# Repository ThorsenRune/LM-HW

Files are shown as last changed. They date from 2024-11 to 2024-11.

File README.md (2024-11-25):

# LM-HW
Design files for the LM project
First Version of the LM Hardware

This hardware is part of a neuroprosthesis aimed at restoring hand function in people with tetraplegia.
It is a two channel emg amplifier and a two channel functional electrical stimulator controlled by the ADUCM360 microcontroller.
These are realized using the Eagle version 7 and produced and assembled by EuroCircuits.
The circuits are tested and functional with some minor bug fixes. 

Bug fixes are available upon request

This part of the LM project has been supported by  The Italian Ministry of Health - Ricerca Corrente, the Promobilia Foundation (Sweden) grant no 16066

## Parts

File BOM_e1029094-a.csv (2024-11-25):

Reference:,"e1029094-a"
Date:,"Fri Jul 20 15:37:21 GMT+200 2018"
Generated by:,"Eurocircuits PCBA Visualizer"
Reference designators | Quantity | MPN | Manufacturer | Description
R30 | 1 | GPR06030R | Generic part | 0 Ohms Jumper 0.1W, 1/10W Chip Resistor 0603 (1608 Metric) Moisture Resistant Thick Film
C75, C76 | 2 | C0603C101K5RACTU | Kemet | Capacitor, Ceramic, 100pF 50V 10% X7R
R9, R10, R11, R24, R56, R57, R65, R68, R69, R70, R71, R72 | 12 | GPR0603100K | Generic part | 0603, Res 100.0kOhm, 50V, 1.0%, 100mW
C44, C50, C190, C191 | 4 | 12062C104KAT2A | AVX | 0.1µF ±10% 200V Ceramic Capacitor X7R 1206 (3216 Metric)
C14, C80, C1U15, C1U16, C2U15, C2U16, C19, C20, C23, C24, C28, C31, C40, C41, C42, C45, C48, C49, C53, C67, C82, C86, C88, C90, C144, CU17 | 26 | GPC0603104 | Generic part | 0603, Cap 100.0nF, 50V, 10.0%, X7R
C55 | 1 | GRM32ER60J107ME20L | Murata | 100µF ±20% 6.3V Ceramic Capacitor X5R 1210 (3225 Metric)
R93 | 1 | GPR060310K | Generic part | 0603, Res 10.0kOhm, 50V, 1.0%, 100mW
R12, R13, R16, R17, R22, R43, R46, R77, R144, R145 | 10 | CRCW060310M0FKEA | Vishay | 10M Ohm ±1% 0.1W, 1/10W Chip Resistor 0603 (1608 Metric) Automotive AEC-Q200 Thick Film
R48, R49 | 2 | GPR060310R | Generic part | 0603, Res 10.0Ohm, 50V, 1.0%, 100mW
R7, R8, R21, R61, R67, R89 | 6 | GPR060310K | Generic part | 0603, Res 10.0kOhm, 50V, 1.0%, 100mW
C32, C33 | 2 | C0603C100J5GACTU | Kemet | 10pF ±5% 50V Ceramic Capacitor C0G, NP0 0603 (1608 Metric)
C1, C2, C4, C6, C7, C8, C9, C16, C29, C30, C38, C52, C54, C58, C59, C81 | 16 | C1608X5R0J106M080AB | TDK | 10µF ±20% 6.3V Ceramic Capacitor X5R 0603 (1608 Metric)
R5, R6, R15, R20 | 4 | GPR0603180K | Generic part | 0603, Res 180.0kOhm, 50V, 1.0%, 100mW
R28, R40, R42, R62 | 4 | GPR06031M | Generic part | 0603, Res 1.0MOhm, 50V, 1.0%, 100mW
R23, R25, R29, R41, R55, R63, R80 | 7 | GPR06031K | Generic part | 0603, Res 1.0kOhm, 50V, 1.0%, 100mW
C10, C10A | 2 | 500R14N102JV4T | Johanson Dielectrics Inc. | 1000pF ±5% 50V Ceramic Capacitor C0G, NP0 0603 (1608 Metric) 0.063" L x 0.032" W (1.60mm x 0.81mm)
C22 | 1 | GPC0603105 | Generic part | 0603, Cap 1uF, 50V, 10.0%, X5R
RSENSE | 1 | MCPWR10FTEQ2000 | Multicomp | RES, THICK FILM, 200R, 1%, 0.75W, 2010
C21, C60, C83, C85 | 4 | C0603C224K3RACTU | Kemet | 0.22µF ±10% 25V Ceramic Capacitor X7R 0603 (1608 Metric)
R3 | 1 | GPR0603270K | Generic part | 0603, Res 270.0kOhm, 50V, 1.0%, 100mW
R1, R4 | 2 | GPR06032M | Generic part | 0603, Res 2.0MOhm, 75V, 1.0%, 100mW
C13, C15, C46, C51, C69, C70 | 6 | C5750X7T2E225K250KE | TDK | 2.2µF ±10% 250V Ceramic Capacitor X7T 2220 (5750 Metric)
L2, L3, L4, L5, L6, L8, L9, L10, L21, L22 | 10 | MMZ1608B301CTAH0 | TDK | FERRITE BEAD 300 OHM 0603 1LN
C11, C12, C17, C18 | 4 | C0603C333K1RACTU | Kemet | 0.033µF ±10% 100V Ceramic Capacitor X7R 0603 (1608 Metric)
R66 | 1 | GPR0603390R | Generic part | 0603, Res 390.0Ohm, 50V, 1.0%, 100mW
R2, R90, R91 | 3 | GPR0603390K | Generic part | 0603, Res 390.0kOhm, 75V, 1.0%, 100mW
R14, R73 | 2 | GPR06033K3 | Generic part | 0603, Res 3.3kOhm, 75V, 1.0%, 100mW
C39 | 1 | CGB3B3X5R0J475K055AB | TDK Corporation | 4.7µF ±10% 6.3V Ceramic Capacitor X5R 0603 (1608 Metric) 0.063" L x 0.032" W (1.60mm x 0.80mm)
R19 | 1 | GPR0603470R | Generic part | 0603, Res 470.0Ohm, 75V, 1.0%, 100mW
C26, C27, C34 | 3 | GPC0603474 | Generic part | 0603, Cap 470nF, 50V, 10.0%, X7R
C3, C5 | 2 | GRM219R60J476ME44D | Murata Electronics North America | 47µF ±20% 6.3V Ceramic Capacitor X5R 0805 (2012 Metric) GRM Series
L11, L12 | 2 | LQH31MN470K03L | Murata | 47µH Unshielded Wirewound Inductor 55mA 10.4 Ohm Max 1206 (3216 Metric)
R18 | 1 | MCWR06X4993FTL | Multicomp | RES, THICK FILM, 499KOHM, 1%, 0.1W, 0603
R64 | 1 | GPR06034K7 | Generic part | 0603, Res 4.7kOhm, 50V, 1.0%, 100mW
C43, C47 | 2 | GRM21BR60J475KA11L | Murata | 4.7µF ±10% 6.3V Ceramic Capacitor X5R 0805 (2012 Metric)
L1 | 1 | B82462G4682M000 | EPCOS | 6.8µH Shielded Wirewound Inductor 1.65A 50 mOhm Max Nonstandard
R51, R58, R83, R84 | 4 | GPR0603820R | Generic part | 0603, Res 820.0Ohm, 50V, 1.0%, 100mW
X1 | 1 | ABS05-32.768KHZ-T | Abracon | 32.768kHz ±20ppm Crystal 12.5pF 90 kOhm -40°C ~ 85°C Surface Mount 2-SMD, No Lead
U4, U18 | 2 | AD8232ACPZ-R7 | Analog Device | ECG Front End IC Heart Rate Monitoring 20-LFCSP-WQ (4x4)
U15, U16, U17 | 3 | AD8642ARMZ | Analog Device | IC OPAMP JFET 3.5MHZ RRO 8MSOP
U1, U2 | 2 | MIC5255-3.3YM5-TR | Microchip | Linear Voltage Regulator IC Positive Fixed 1 Output 3.3V 150mA SOT-23-5
U5 | 1 | ADUCM360BCPZ128 | Analog Device | ARM® Cortex®-M3 ADuCM Microcontroller IC 32-Bit 20 MIPS 128KB (128K x 8) FLASH 48-LFCSP-WQ (7x7)
RL3, RL4, RL5, RL6, RL7, RL8, RL9, RL10, RL11, RL12 | 10 | AQY210S | Panasonic | MOSFET Relay, 350 V, 120 mA, 25 ohm, SPST-NO
TR1 | 1 | ATB322524-0110 | TDK | Audio Transformers / Signal Transformers Photoflash Capacitor Charging Transformer
D2, D8, D12, D22 | 4 | BAS40-04W,115 | NXP Semiconductors | Diode Array 1 Pair Series Connection Schottky 40V 120mA (DC) Surface Mount SC-70, SOT-323
D1 | 1 | BAV23S,215 | Nexperia | Diode Array 1 Pair Series Connection Standard 200V 225mA (DC) Surface Mount TO-236-3, SC-59, SOT-23-3
D6N, D6P, D6P1, D6P2 | 4 | BAV3004W-7-F | Diode Inc | Diode Standard 300V 225mA (DC) Surface Mount SOD-123
F1 | 1 | 0805L100WR | Littelfuse | Polymeric PTC Resettable Fuse 6V 1A Ih Surface Mount 0805 (2012 Metric), Concave
ZD1, ZD3 | 2 | KDZLVTFTR150 | ROHM Semiconductor | Zener Diode 150V 1W Surface Mount SOD-123FL
U13 | 1 | LT3484EDCB-1#TRMPBF | Linear Technology/Analog Devices | Photoflash Capacitor Charger PMIC 6-DFN (2x3)
X6 | 1 | 9-215464-0 | TE Connectivity | Connector Header Through Hole 20 position 0.100" (2.54mm)
X4 | 1 | 7-215464-8 | TE Connectivity | Connector Header Through Hole 8 position 0.100" (2.54mm)
IC1 | 1 | OPA340NA/3K | Texas Instruments | General Purpose Amplifier 1 Circuit Rail-to-Rail SOT-23-5
PMOS1 | 1 | SIS406DN-T1-GE3 | Vishay | N-Channel MOSFET 30V 9A (Ta) 1.5W (Ta) Surface Mount PowerPAK® 1212-8
IC17 | 1 | TPS60400DBVR | Texas Instruments | IC, Unregulated 60mA Charge Pump Voltage Inverter
U3 | 1 | TPS61020DRCRG4 | Texas Instrument | DC-DC Switching Boost Step Up Regulator, Adjustable, 900mV-6.5Vin, 1.8V-5.5Vout, 200mAout, SON-10
D21 | 1 | ZHCS400 | Diode Inc | Diode Schottky 40V 400mA (DC) Surface Mount SOD-323
T4 | 1 | ZVN4525ZTA | Diode Inc | N-Channel MOSFET 250V 240mA (Ta) 1.2W (Ta) Surface Mount SOT-89-3
T25 | 1 | ZVP4525ZTA | Diodes Incorporated | P-Channel MOSFET 250V 205mA (Ta) 1.2W (Ta) Surface Mount SOT-89-3

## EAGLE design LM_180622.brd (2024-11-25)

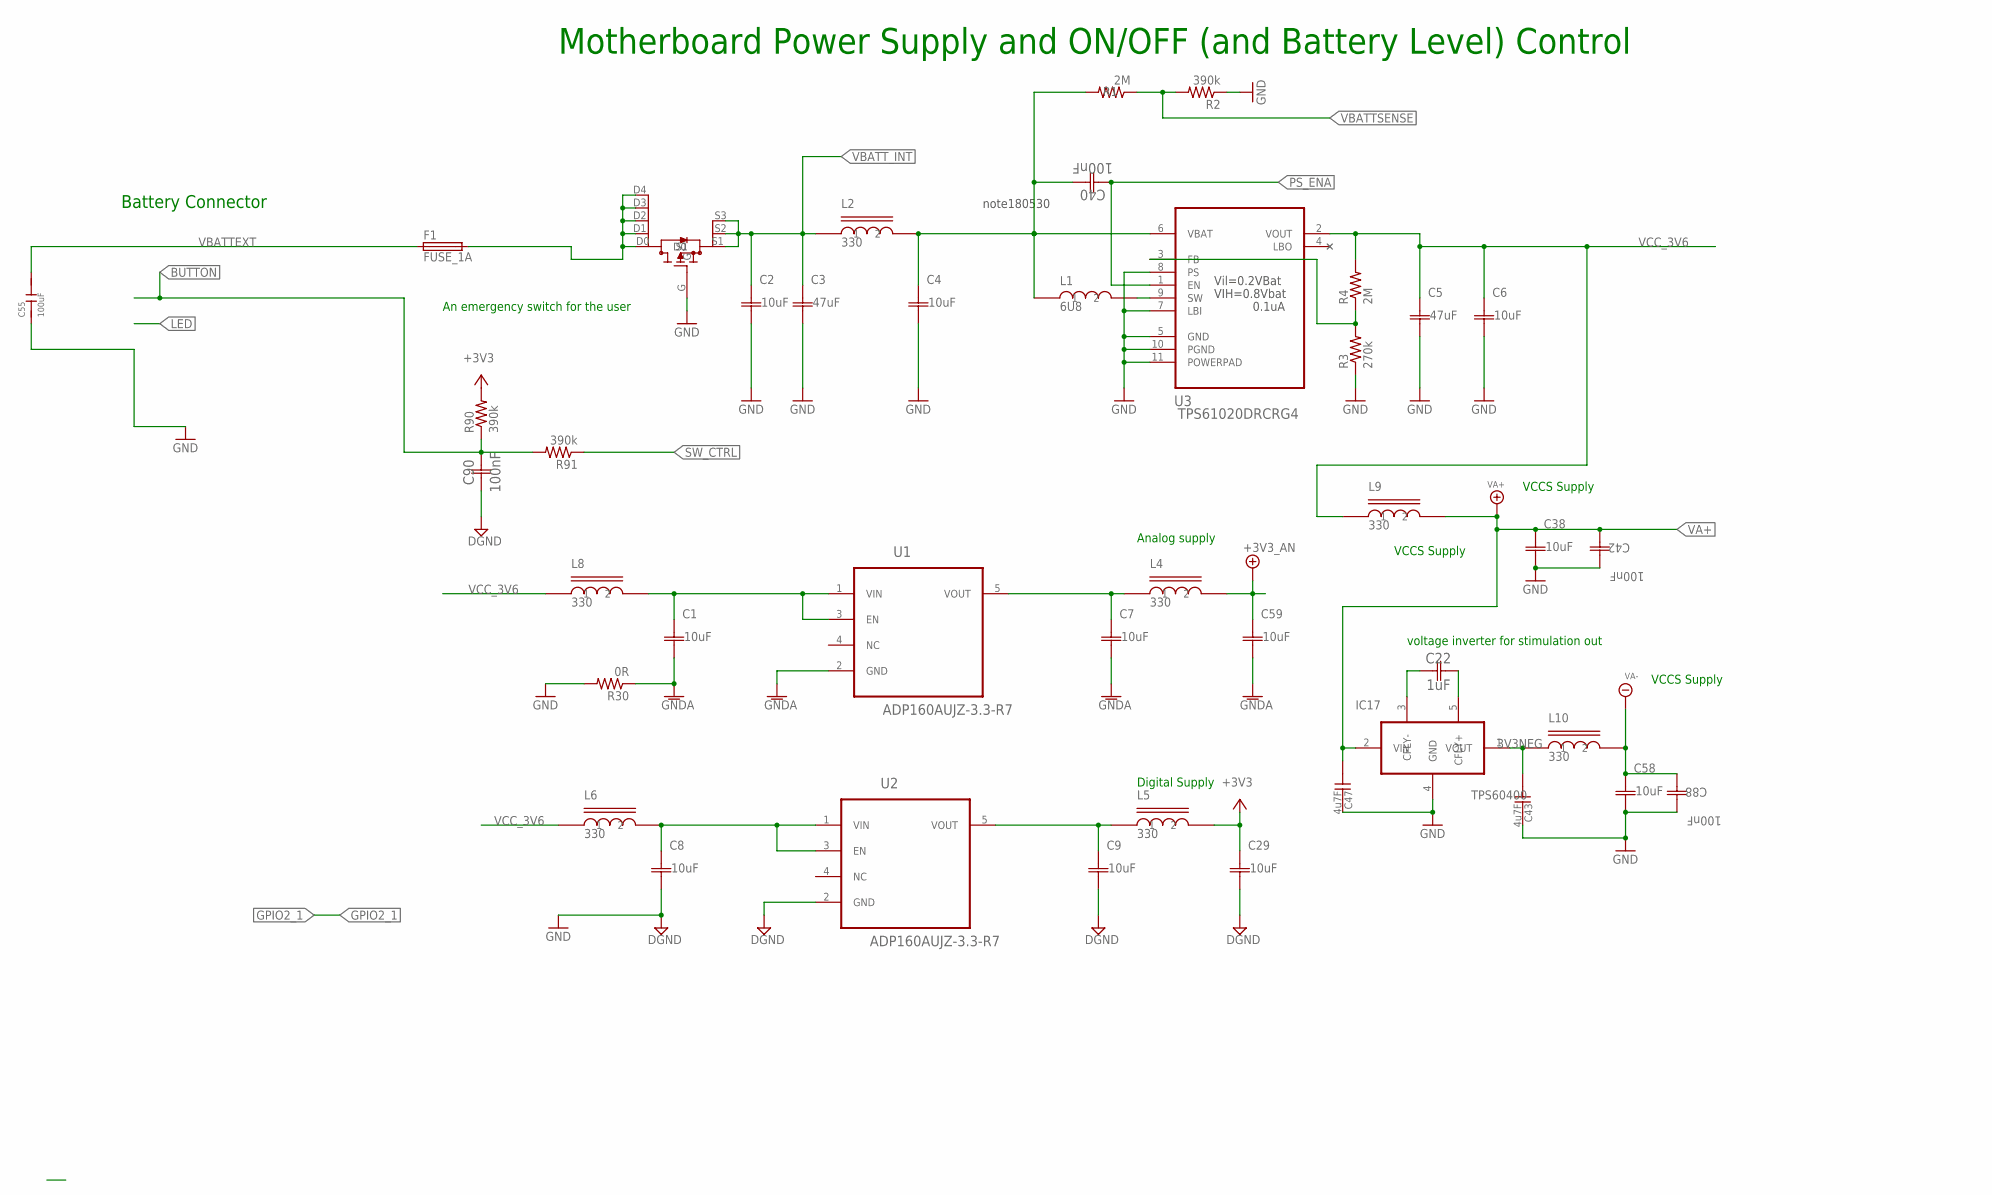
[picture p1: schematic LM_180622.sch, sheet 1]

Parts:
C1, C2, C4, C6, C7, C8, C9, C29, C38, C58, C59: 10uF; C0603
C3, C5: 47uF; C0805
C22: 1uF; 0603-CAP
C40, C42, C88, C90: 100nF; C0603
C43, C47: 4u7F; C0805
C55: 100uF; C1210; MPN JMK325BJ107MY-T
F1: FUSE_1A; C0805
IC17: TPS60400; SOT23-5; MPN TPS60400DBVR
L1: 6U8; SMT_POWER_IND_B82462G4; MPN B82462G4682M000
L2, L4, L5, L6, L8, L9, L10: 330; L0603; PARTNO MMZ1608B301C
PMOS1: SIS407DN; POWERPAK1212-8SINGLE
R1, R4: 2M; R0603
R2, R90, R91: 390k; R0603
R3: 270k; R0603; MPN MC0603N270K500CT
R30: 0R; R0603
U1, U2: ADP160AUJZ-3.3-R7; SOT95P280X100-5N; MPN MIC5255-3.3YM5-TR
U3: TPS61020DRCRG4; SON50P300X300X100-11N

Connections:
3V3NEG: C43.1, IC17.1 (VOUT), L10.1
+3V3: C29.2 (C2), L5.2, R90.2; also elsewhere on the board
+3V3_AN: C59.2 (C2), L4.2; also elsewhere on the board
A3V6: C1.2 (C2), L8.2, U1.1 (VIN), U1.3 (EN)
BUTTON: C90.2 (C2), R90.1, R91.2; also elsewhere on the board
FB_3V6: R3.2, R4.1, U3.3 (FB)
GND: C2.1 (C1), C3.1 (C1), C4.1 (C1), C5.1 (C1), C6.1 (C1), C8.1 (C1), C9.1 (C1), C29.1 (C1), C38.1 (C1), C42.2 (C2), C43.2, C47.2, C55.1, C58.1 (C1), C88.2 (C2), C90.1 (C1), IC17.4 (GND), PMOS1.G, R2.1, R3.1, R30.2, U2.2 (GND), U3.5 (GND), U3.7 (LBI), U3.8 (PS), U3.10 (PGND), U3.11 (POWERPAD); also elsewhere on the board
GNDA: C1.1 (C1), C7.1 (C1), C59.1 (C1), R30.1, U1.2 (GND); also elsewhere on the board
unnamed: F1.2, PMOS1.D0, PMOS1.D1, PMOS1.D2, PMOS1.D3, PMOS1.D4
unnamed: L1.2, U3.9 (SW)
unnamed: C7.2 (C2), L4.1, U1.5 (VOUT)
unnamed: C9.2 (C2), L5.1, U2.5 (VOUT)
unnamed: C8.2 (C2), L6.2, U2.1 (VIN), U2.3 (EN)
unnamed: C22.1 (C1), IC17.3 (CFLY-)
unnamed: C22.2 (C2), IC17.5 (CFLY+)
PS_ENA: C40.1 (C1), U3.1 (EN); also elsewhere on the board
SW_CTRL: R91.1; also elsewhere on the board
VA+: C38.2 (C2), C42.1 (C1), C47.1, IC17.2 (VIN), L9.2; also elsewhere on the board
VA-: C58.2 (C2), C88.1 (C1), L10.2; also elsewhere on the board
VBATTEXT: C55.2, F1.1; also elsewhere on the board
VBATTSENSE: R1.1, R2.2; also elsewhere on the board
VBATT_INT: C2.2 (C2), C3.2 (C2), L2.1, PMOS1.S1, PMOS1.S2, PMOS1.S3; also elsewhere on the board
VBATU3: C4.2 (C2), C40.2 (C2), L1.1, L2.2, R1.2, U3.6 (VBAT)
VCC_3V6: C5.2 (C2), C6.2 (C2), L6.1, L8.1, L9.1, R4.2, U3.2 (VOUT)

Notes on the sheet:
Motherboard Power Supply and ON/OFF (and Battery Level) Control
Battery Connector
An emergency switch for the user
voltage inverter for stimulation out
note180530
Vil=0.2VBat
VIH=0.8Vbat
0.1uA
Digital Supply
Analog supply
VCCS Supply

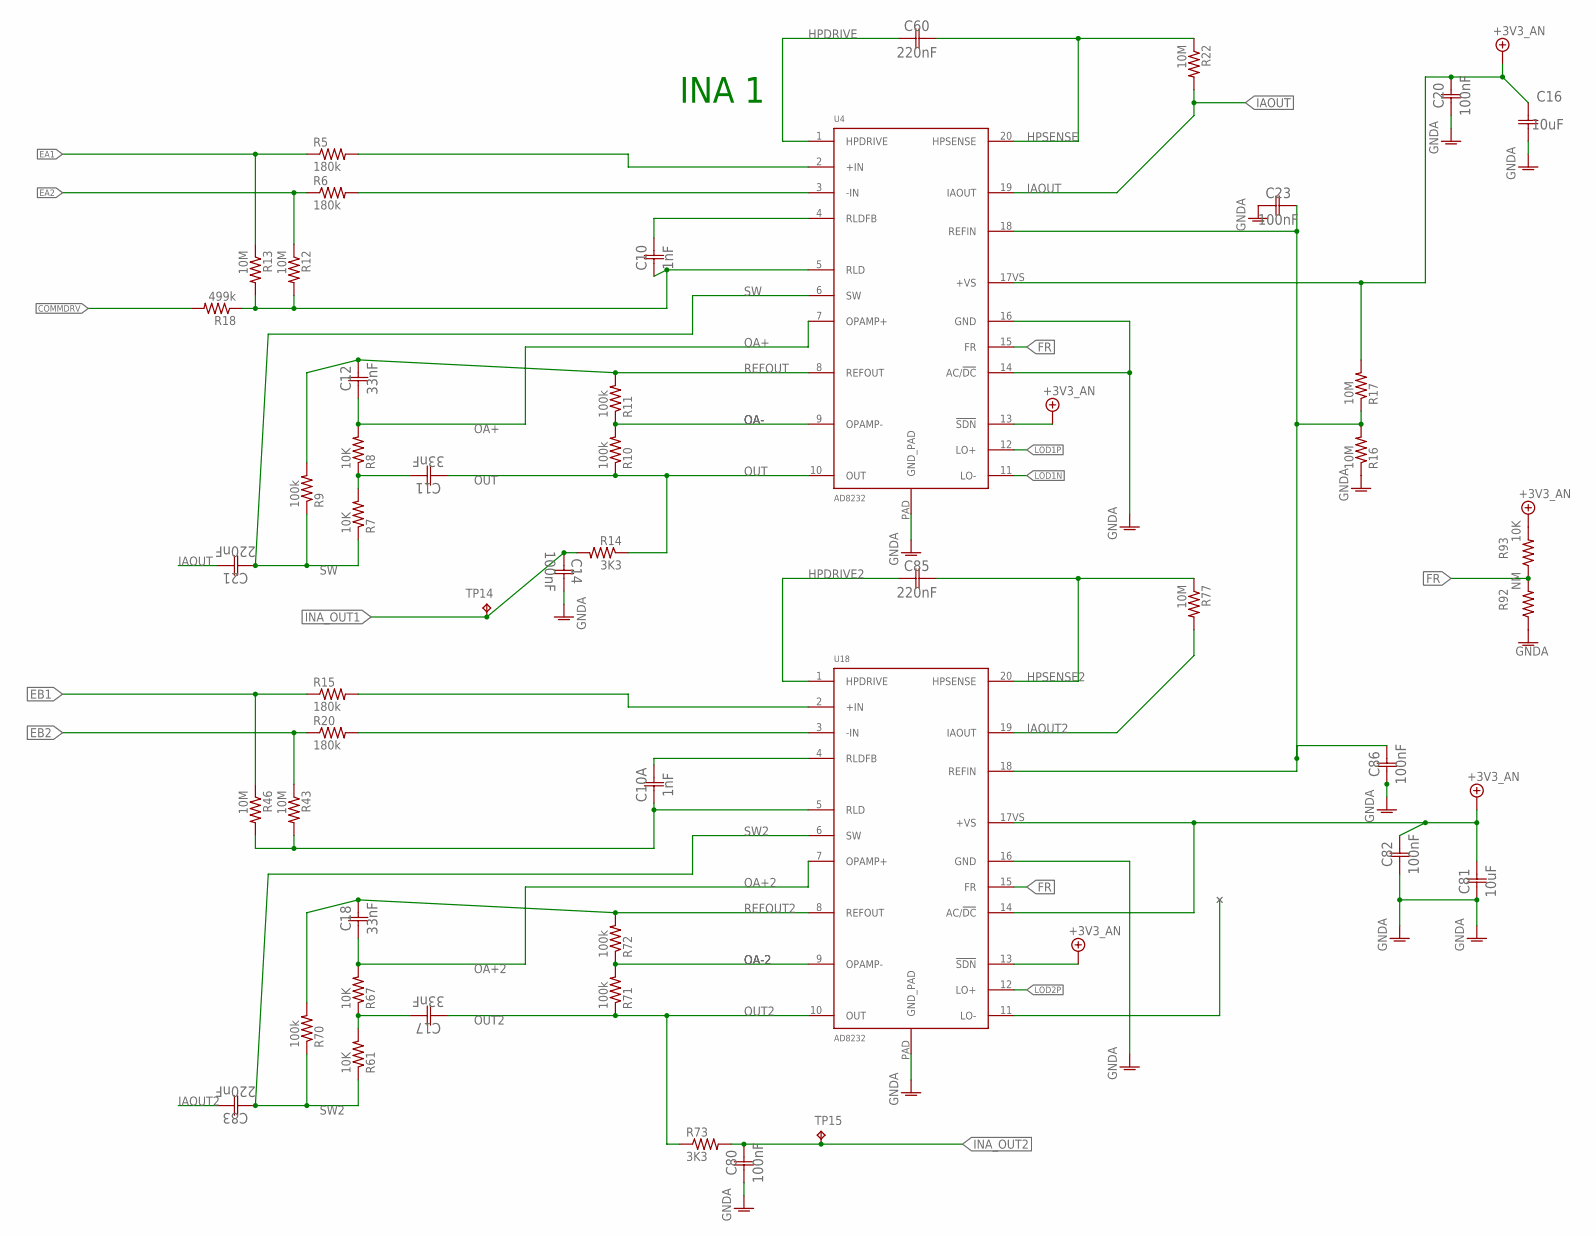
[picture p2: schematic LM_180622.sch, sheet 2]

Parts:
C10, C10A: 1nF; C0603
C11, C12, C17, C18: 33nF; C0603
C14, C20, C23, C80, C82, C86: 100nF; C0603
C16, C81: 10uF; C0603
C21, C60, C83, C85: 220nF; C0603
R5, R6, R15, R20: 180k; R0603
R7, R8, R61, R67, R93: 10K; R0603
R9, R10, R11, R70, R71, R72: 100k; R0603
R12, R13, R16, R17, R22, R43, R46, R77: 10M; R0603
R14, R73: 3K3; R0603
R18: 499k; R0603; MPN CRCW0201499KFKED
R92: NM; R0603
TP14, TP15: NM; B1,27
U4, U18: AD8232; LFCSP_20

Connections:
+3V3_AN: C16.2 (C2), C20.1 (C1), C81.2 (C2), C82.1 (C1), R17.2, R93.2, U4.13 (!SDN), U4.17VS (+VS), U18.13 (!SDN), U18.14 (AC/!DC), U18.17VS (+VS); also elsewhere on the board
COMMDRV: R18.2; also elsewhere on the board
EA1: R5.1, R13.1; also elsewhere on the board
EA2: R6.1, R12.1; also elsewhere on the board
EB1: R15.1, R46.1; also elsewhere on the board
EB2: R20.1, R43.1; also elsewhere on the board
FR: R92.2, R93.1, U4.15 (FR), U18.15 (FR)
GNDA: C14.2 (C2), C16.1 (C1), C20.2 (C2), C23.2 (C2), C80.2 (C2), C81.1 (C1), C82.2 (C2), C86.2 (C2), R16.1, R92.1, U4.14 (AC/!DC), U4.16 (GND), U4.PAD (GND_PAD), U18.16 (GND), U18.PAD (GND_PAD); also elsewhere on the board
HPDRIVE: C60.1 (C1), U4.1 (HPDRIVE)
HPDRIVE2: C85.1 (C1), U18.1 (HPDRIVE)
HPSENSE: C60.2 (C2), R22.1, U4.20 (HPSENSE)
HPSENSE2: C85.2 (C2), R77.1, U18.20 (HPSENSE)
IAOUT: C21.1 (C1), R22.2, U4.19 (IAOUT)
IAOUT2: C83.1 (C1), R77.2, U18.19 (IAOUT)
INA_OUT1: C14.1 (C1), R14.2, TP14.TP; also elsewhere on the board
INA_OUT2: C80.1 (C1), R73.2, TP15.TP; also elsewhere on the board
LOD1N: U4.11 (LO-); also elsewhere on the board
LOD1P: U4.12 (LO+); also elsewhere on the board
LOD2P: U18.12 (LO+); also elsewhere on the board
unnamed: R5.2, U4.2 (+IN)
unnamed: R6.2, U4.3 (-IN)
unnamed: C11.1 (C1), R7.2, R8.1
unnamed: C10A.2 (C2), U18.4 (RLDFB)
unnamed: C10A.1 (C1), R43.2, R46.2, U18.5 (RLD)
unnamed: C10.2 (C2), U4.4 (RLDFB)
unnamed: C10.1 (C1), R12.2, R13.2, R18.1, U4.5 (RLD)
unnamed: R15.2, U18.2 (+IN)
unnamed: R20.2, U18.3 (-IN)
unnamed: C17.1 (C1), R61.2, R67.1
OA+: C12.2 (C2), R8.2, U4.7 (OPAMP+)
OA+2: C18.2 (C2), R67.2, U18.7 (OPAMP+)
OA-: R10.2, R11.1, U4.9 (OPAMP-)
OA-2: R71.2, R72.1, U18.9 (OPAMP-)
OUT: C11.2 (C2), R10.1, R14.1, U4.10 (OUT)
OUT2: C17.2 (C2), R71.1, R73.1, U18.10 (OUT)
REFOUT: C12.1 (C1), R9.2, R11.2, U4.8 (REFOUT)
REFOUT2: C18.1 (C1), R70.2, R72.2, U18.8 (REFOUT)
SW: C21.2 (C2), R7.1, R9.1, U4.6 (SW)
SW2: C83.2 (C2), R61.1, R70.1, U18.6 (SW)
VREFIN: C23.1 (C1), C86.1 (C1), R16.2, R17.1, U4.18 (REFIN), U18.18 (REFIN)

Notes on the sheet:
INA 1

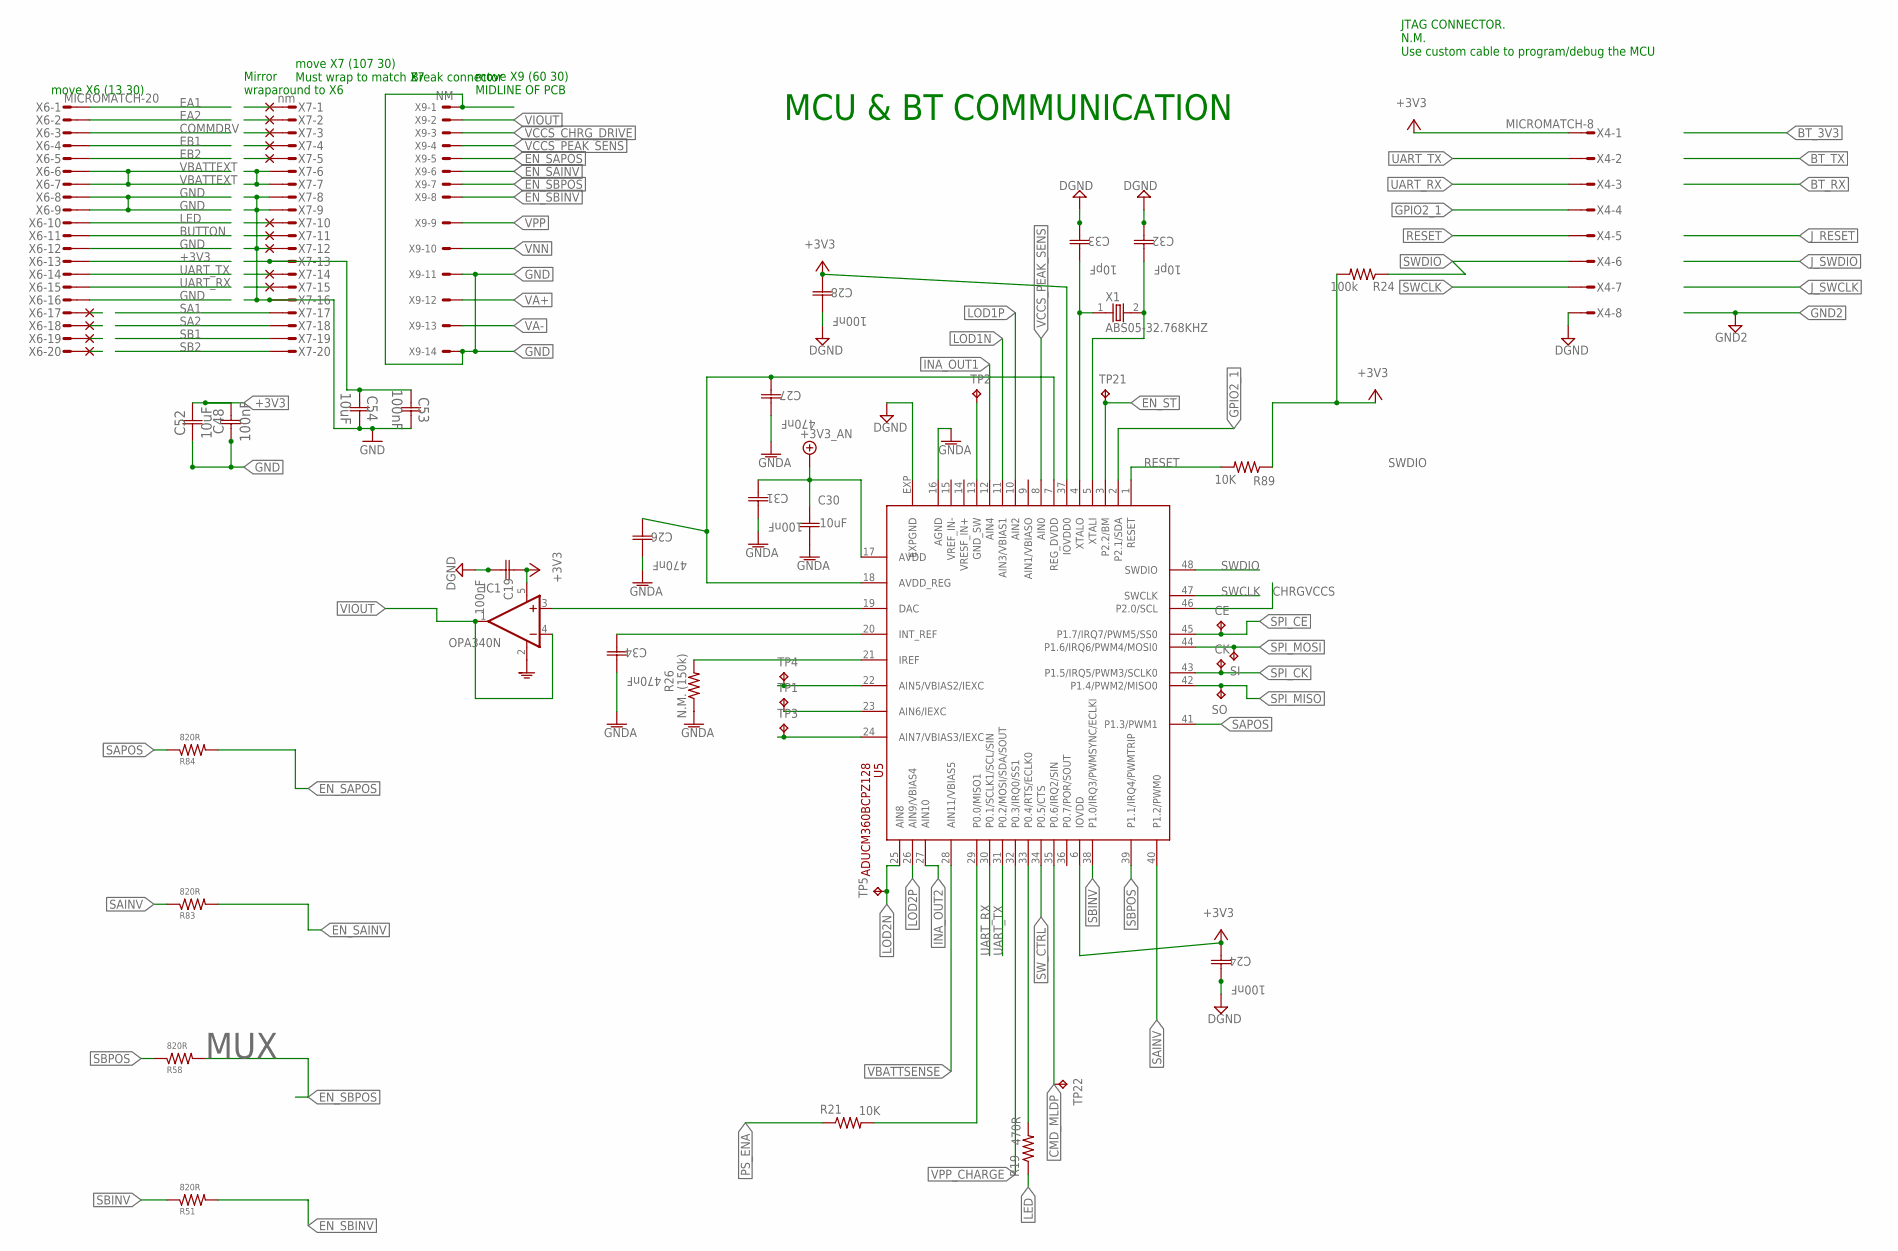
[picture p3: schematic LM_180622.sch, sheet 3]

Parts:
C19, C24, C28, C31, C48, C53: 100nF; C0603
C26, C27, C34: 470nF; C0603
C30, C52, C54: 10uF; C0603
C32, C33: 10pF; C0603
CE: NM; TH0305
CK: NM; TH0305
IC1: OPA340N; SOT23-5; MPN OPA340NA/3K
R19: 470R; R0603; MPN ERJ3EKF4700V
R21, R89: 10K; R0603
R24: 100k; R0603
R26: N.M. (150k); R0603
R51, R58, R83, R84: 820R; R0603
SI: NM; TH0305
SO: NM; TH0305
TP1, TP2, TP3, TP4, TP5, TP21, TP22: NM; TH0305
U5: ADUCM360BCPZ128; LFCSP48; MPN ADUCM360BCPZ128
X1: ABS05-32.768KHZ; CRYSTAL-2PIN
X4: MICROMATCH-8
X6: MICROMATCH-20; MPN 2-215079-0
X7: nm; MICROMATCH-20
X9: NM; 70543-14

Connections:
3V3_BT: C53.2 (C2), C54.1 (C1), X7.13
+3V3: C19.1 (C1), C24.1 (C1), C28.1 (C1), C48.1 (C1), C52.2 (C2), IC1.5 (V+), R24.2, R89.1, U5.6 (IOVDD), U5.37 (IOVDD0), X4.1, X6.13; also elsewhere on the board
+3V3_AN: C30.2 (C2), C31.1 (C1), U5.17 (AVDD); also elsewhere on the board
BUTTON: X6.11; also elsewhere on the board
CHRGVCCS: U5.46 (P2.0/SCL); also elsewhere on the board
CMD_MLDP: TP22.TP, U5.35 (P0.6/IRQ2/SIN)
COMMDRV: X6.3; also elsewhere on the board
EA1: X6.1; also elsewhere on the board
EA2: X6.2; also elsewhere on the board
EB1: X6.4; also elsewhere on the board
EB2: X6.5; also elsewhere on the board
EN_SAINV: R83.2, X9.6; also elsewhere on the board
EN_SAPOS: R84.2, X9.5; also elsewhere on the board
EN_SBINV: R51.2, X9.8; also elsewhere on the board
EN_SBPOS: R58.2, X9.7; also elsewhere on the board
EN_ST: TP21.TP, U5.3 (P2.2/BM)
GND: C19.2 (C2), C24.2 (C2), C28.2 (C2), C32.1 (C1), C33.1 (C1), C48.2 (C2), C52.1 (C1), C53.1 (C1), C54.2 (C2), IC1.2 (V-), U5.EXP (EXPGND), X4.8, X6.8, X6.9, X6.12, X6.16, X7.8, X7.9, X7.12, X7.16, X9.1, X9.11, X9.14; also elsewhere on the board
GNDA: C26.2 (C2), C27.2 (C2), C30.1 (C1), C31.2 (C2), C34.2 (C2), R26.1, U5.16 (AGND); also elsewhere on the board
GPIO2_1: U5.2 (P2.1/SDA), X4.4
INA_OUT1: U5.12 (AIN4); also elsewhere on the board
INA_OUT2: U5.27 (AIN10); also elsewhere on the board
LED: R19.1, X6.10
LED_CTRL1: R19.2, U5.33 (P0.4/RTS/ECLK0)
LOD1N: U5.11 (AIN3/VBIAS1); also elsewhere on the board
LOD1P: U5.10 (AIN2); also elsewhere on the board
LOD2N: TP5.TP, U5.25 (AIN8)
LOD2P: U5.26 (AIN9/VBIAS4); also elsewhere on the board
unnamed: C33.2 (C2), U5.4 (XTALO), X1.1
unnamed: C26.1 (C1), C27.1 (C1), U5.7 (REG_DVDD), U5.18 (AVDD_REG)
unnamed: TP1.TP, U5.23 (AIN6/IEXC)
unnamed: C32.2 (C2), U5.5 (XTALI), X1.2
unnamed: R26.2, U5.21 (IREF)
unnamed: C34.1 (C1), U5.20 (INT_REF)
unnamed: R21.2, U5.29 (P0.0/MISO1)
unnamed: TP2.TP, U5.13 (GND_SW)
unnamed: X7.6, X7.7
unnamed: IC1.3 (+IN), U5.19 (DAC)
unnamed: TP3.TP, U5.24 (AIN7/VBIAS3/IEXC)
unnamed: TP4.TP, U5.22 (AIN5/VBIAS2/IEXC)
PS_ENA: R21.1; also elsewhere on the board
RESET: R89.2, U5.1 (RESET), X4.5
SA1: X7.17; also elsewhere on the board
SA2: X7.18; also elsewhere on the board
SAINV: R83.1, U5.40 (P1.2/PWM0)
SAPOS: R84.1, U5.41 (P1.3/PWM1)
SB1: X7.19; also elsewhere on the board
SB2: X7.20; also elsewhere on the board
SBINV: R51.1, U5.38 (P1.0/IRQ3/PWMSYNC/ECLKI)
SBPOS: R58.1, U5.39 (P1.1/IRQ4/PWMTRIP)
SPI_CE: CE.TP, U5.45 (P1.7/IRQ7/PWM5/SS0)
SPI_CK: CK.TP, U5.43 (P1.5/IRQ5/PWM3/SCLK0)
SPI_MISO: SO.TP, U5.42 (P1.4/PWM2/MISO0)
SPI_MOSI: SI.TP, U5.44 (P1.6/IRQ6/PWM4/MOSI0)
SWCLK: U5.47 (SWCLK), X4.7
SWDIO: R24.1, U5.48 (SWDIO), X4.6
SW_CTRL: U5.34 (P0.5/CTS); also elsewhere on the board
UART_RX: U5.30 (P0.1/SCLK1/SCL/SIN), X4.3, X6.15
UART_TX: U5.31 (P0.2/MOSI/SDA/SOUT), X4.2, X6.14
VA+: X9.12; also elsewhere on the board
VA-: X9.13; also elsewhere on the board
VBATTEXT: X6.6, X6.7; also elsewhere on the board
VBATTSENSE: U5.28 (AIN11/VBIAS5); also elsewhere on the board
VCCS_CHRG_DRIVE: X9.3; also elsewhere on the board
VCCS_PEAK_SENS: U5.8 (AIN0), X9.4; also elsewhere on the board
VIOUT: IC1.1 (OUT), IC1.4 (-IN), X9.2; also elsewhere on the board
VNN: X9.10; also elsewhere on the board
VPP: X9.9; also elsewhere on the board
VPP_CHARGE: U5.32 (P0.3/IRQ0/SS1); also elsewhere on the board

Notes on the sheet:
MCU & BT COMMUNICATION
JTAG CONNECTOR. N.M. Use custom cable to program/debug the MCU
MUX
Break connector
Mirror wraparound to X6
move X9 (60 30) MIDLINE OF PCB
move X6 (13 30)
move X7 (107 30) Must wrap to match X7

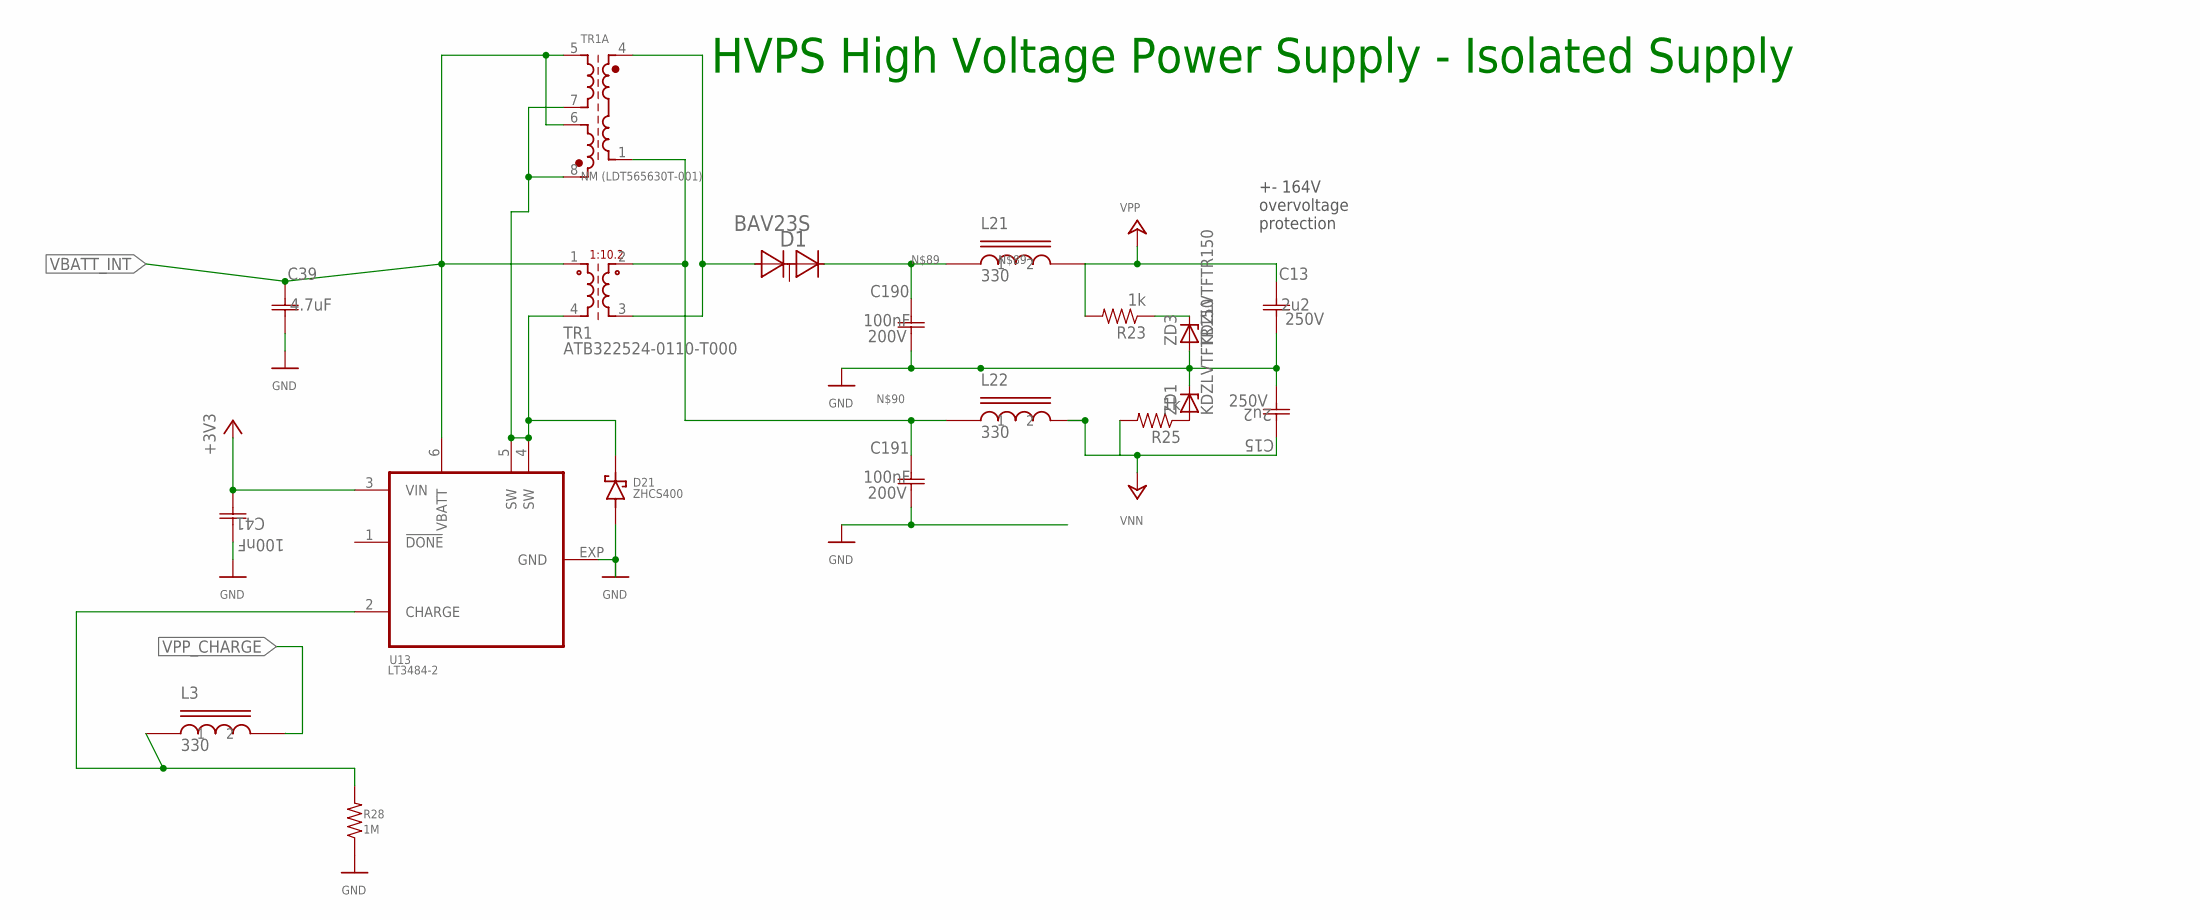
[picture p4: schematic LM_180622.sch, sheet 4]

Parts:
C13, C15: 2u2; C2220K; MPN ECA-2GHG2R2
C39: 4.7uF; C0603
C41: 100nF; C0603
C190, C191: 100nF; 1206
D1: BAV23S; SOT23; MPN BAV23S-7-F
D21: ZHCS400; SOD323
L3, L21, L22: 330; L0603; PARTNO MMZ1608B301C
R23, R25: 1k; R0603
R28: 1M; R0603
TR1: ATB322524-0110-T000; 3225_4PIN
TR1A: NM (LDT565630T-001); SM-E6
U13: LT3484-2; DFN6-2X3
ZD1, ZD3: KDZLVTFTR150; SOD123

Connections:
+3V3: C41.1 (C1), U13.3 (VIN); also elsewhere on the board
GND: C13.1 (C1), C15.1 (C1), C39.1 (C1), C41.2 (C2), C190.1 (C1), C191.1 (C1), D21.A (1A), R28.1, U13.EXP (GND), ZD1.1C (C), ZD3.2A (A); also elsewhere on the board
LT_CHRG: L3.1, R28.2, U13.2 (CHARGE)
unnamed: R23.1, ZD3.1C (C)
unnamed: R25.1, ZD1.2A (A)
unnamed: D1.1, TR1.3, TR1A.4
unnamed: C190.2 (C2), D1.2, L21.1
unnamed: C191.2 (C2), L22.1, TR1.2, TR1A.1
N_SW2: D21.K (2C), TR1.4, TR1A.7, TR1A.8, U13.4 (SW), U13.5 (SW)
VBATT_INT: C39.2 (C2), TR1.1, TR1A.5, TR1A.6, U13.6 (VBATT); also elsewhere on the board
VNN: C15.2 (C2), L22.2, R25.2; also elsewhere on the board
VPP: C13.2 (C2), L21.2, R23.2; also elsewhere on the board
VPP_CHARGE: L3.2; also elsewhere on the board

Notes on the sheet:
HVPS High Voltage Power Supply - Isolated Supply
+- 164V overvoltage protection

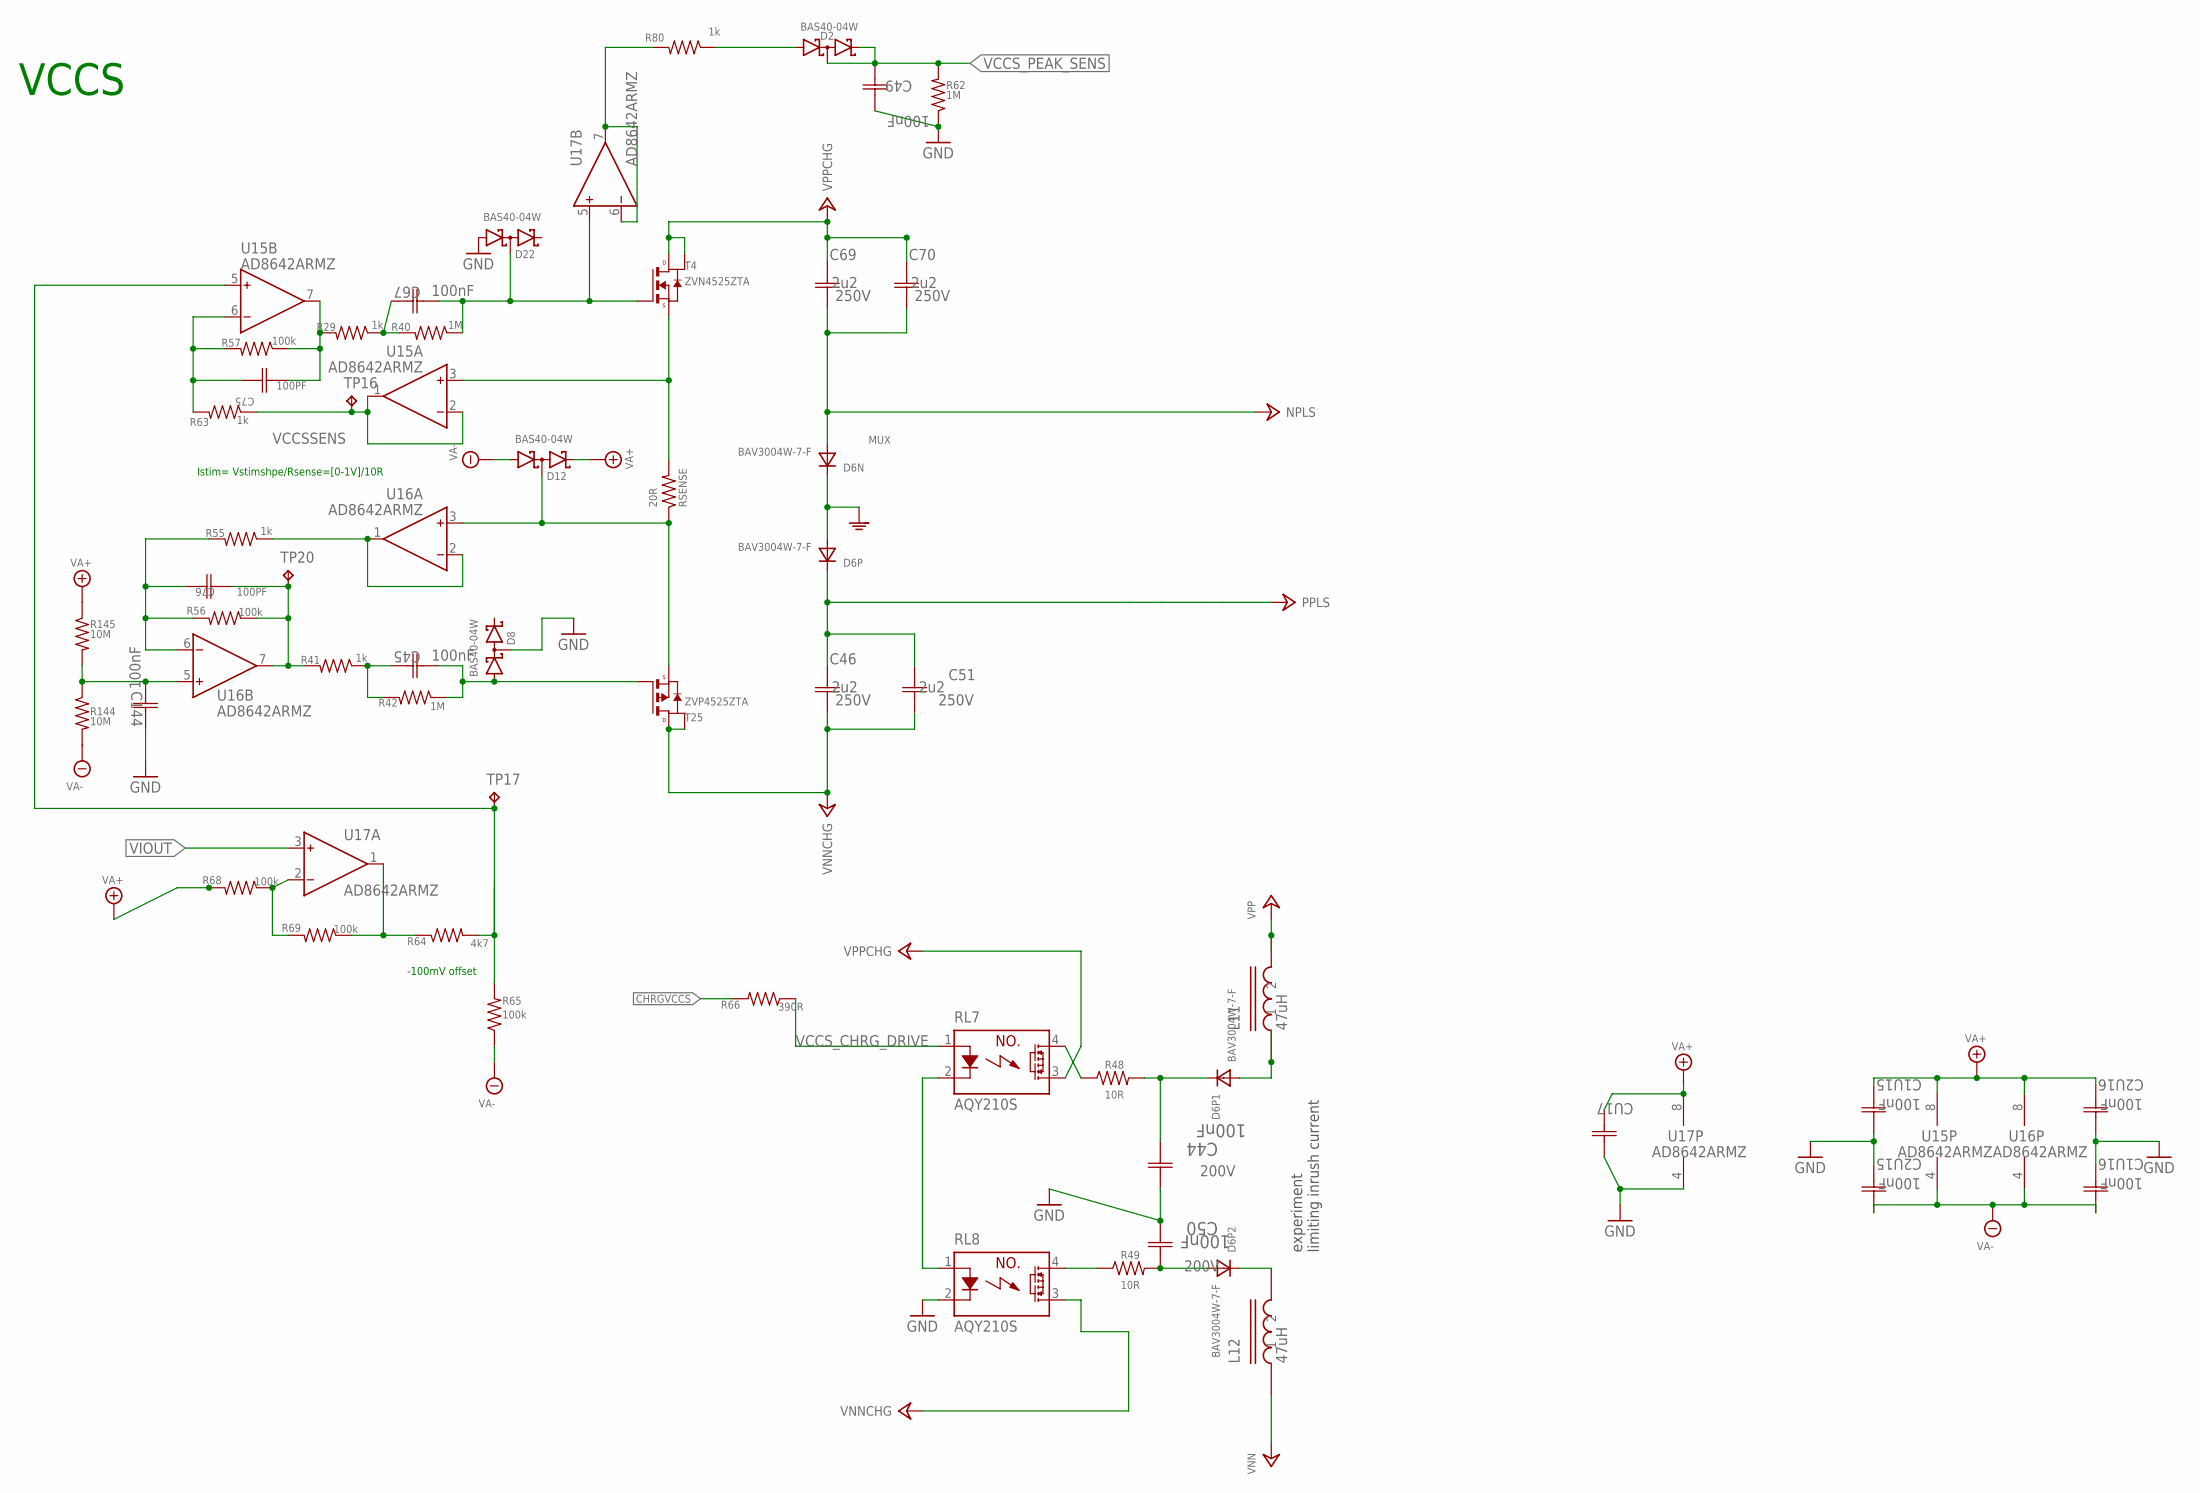
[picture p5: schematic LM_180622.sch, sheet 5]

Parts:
C1U15, C1U16, C2U15, C2U16, C45, C49, C67, C144: 100nF; C0603
C44, C50: 100nF; 1206
C46, C51, C69, C70: 2u2; C2220K; MPN ECA-2GHG2R2
C75, C76: 100PF; C0603
CU17: 100nF; C0603
D2, D8, D12, D22: BAS40-04W; SOT323; MPN BAS40-04W 115.
D6N, D6P, D6P1, D6P2: BAV3004W-7-F; SOD123
L11, L12: 47uH; 1206
R29, R41, R55, R63, R80: 1k; R0603
R40, R42, R62: 1M; R0603
R48, R49: 10R; R0603
R56, R57, R65, R68, R69: 100k; R0603
R64: 4k7; R0603
R66: 390R; R0603
R144, R145: 10M; R0603
RL7, RL8: AQY210S; SOP04; MPN AQY210SX
RSENSE: 20R; R2010
T4: ZVN4525ZTA; SOT89
T25: ZVP4525ZTA; SOT89
TP16, TP17, TP20: NM; TH0305
U15, U16, U17: AD8642ARMZ; MSOP8

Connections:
CHRGVCCS: R66.2; also elsewhere on the board
GND: C1U15.1 (C1), C1U16.2 (C2), C2U15.2 (C2), C2U16.1 (C1), C44.1 (C1), C49.2 (C2), C50.2 (C2), C144.1 (C1), CU17.1 (C1), D6N.C, D6P.A, D8.3 (C1A2), D22.1 (A1), R62.1, RL8.2 (K), U17.4 (V-); also elsewhere on the board
unnamed: C75.2 (C2), R29.2, R57.1, U15.7 (OUT)
unnamed: R80.2, U17.6 (IN-), U17.7 (OUT)
unnamed: D6P2.C, L12.2
unnamed: C50.1 (C1), D6P2.A, R49.2
unnamed: D6P1.A, L11.1
unnamed: C44.2 (C2), D6P1.C, R48.2
unnamed: C76.2 (C2), R41.2, R56.1, TP20.TP, U16.7 (OUT)
unnamed: R55.1, U16.1 (OUT), U16.2 (IN-)
unnamed: C76.1 (C1), R55.2, R56.2, U16.6 (IN-)
unnamed: C75.1 (C1), R57.2, R63.2, U15.6 (IN-)
unnamed: R64.1, R69.1, U17.1 (OUT)
unnamed: C144.2 (C2), R144.1, R145.2, U16.5 (IN+)
unnamed: C67.1 (C1), R29.1, R40.2
unnamed: R68.1, R69.2, U17.2 (IN-)
unnamed: R49.1, RL8.4 (DS1)
unnamed: D2.1 (A1), R80.1
unnamed: R48.1, RL7.4 (DS1)
unnamed: C45.1 (C1), R41.1, R42.2
NAQY: RL7.2 (K), RL8.1 (A)
NG1B: C67.2 (C2), D22.3 (C1A2), R40.1, T4.1 (G), U17.5 (IN+)
NG1B1: C45.2 (C2), D8.1 (A1), R42.1, T25.1 (G)
NPLS: C69.1 (C1), C70.1 (C1), D6N.A; also elsewhere on the board
NS1A: D12.3 (C1A2), RSENSE.1, T25.3 (S), U16.3 (IN+)
NSB: RSENSE.2, T4.3 (S), U15.3 (IN+)
PLSCTRL1: R64.2, R65.2, TP17.TP, U15.5 (IN+)
PPLS: C46.2 (C2), C51.2 (C2), D6P.C; also elsewhere on the board
VA+: C1U15.2 (C2), C2U16.2 (C2), CU17.2 (C2), D12.2 (C2), R68.2, R145.1, U15.8 (V+), U16.8 (V+), U17.8 (V+); also elsewhere on the board
VA-: C1U16.1 (C1), C2U15.1 (C1), D12.1 (A1), R65.1, R144.2, U15.4 (V-), U16.4 (V-); also elsewhere on the board
VCCSSENS: R63.1, TP16.TP, U15.1 (OUT), U15.2 (IN-)
VCCS_CHRG_DRIVE: R66.1, RL7.1 (A); also elsewhere on the board
VCCS_PEAK_SENS: C49.1 (C1), D2.2 (C2), D2.3 (C1A2), R62.2; also elsewhere on the board
VIOUT: U17.3 (IN+); also elsewhere on the board
VNN: L12.1; also elsewhere on the board
VNNCHG: C46.1 (C1), C51.1 (C1), RL8.3 (DS2), T25.2 (D2), T25.4 (D3)
VPP: L11.2; also elsewhere on the board
VPPCHG: C69.2 (C2), C70.2 (C2), RL7.3 (DS2), T4.2 (D1), T4.4 (D2)

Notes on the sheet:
VCCS
Istim= Vstimshpe/Rsense=[0-1V]/10R
MUX
-100mV offset
experiment limiting inrush current

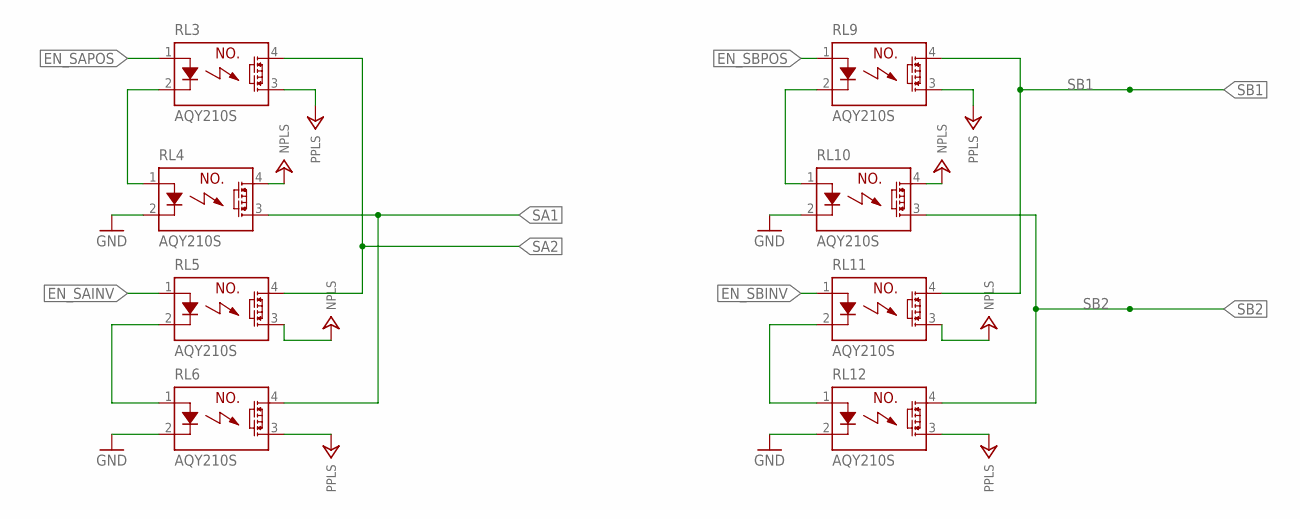
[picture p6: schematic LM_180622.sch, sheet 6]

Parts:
RL3, RL4, RL5, RL6, RL9, RL10, RL11, RL12: AQY210S; SOP04; MPN AQY210SX

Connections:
EN_SAINV: RL5.1 (A); also elsewhere on the board
EN_SAPOS: RL3.1 (A); also elsewhere on the board
EN_SBINV: RL11.1 (A); also elsewhere on the board
EN_SBPOS: RL9.1 (A); also elsewhere on the board
GND: RL4.2 (K), RL6.2 (K), RL10.2 (K), RL12.2 (K); also elsewhere on the board
unnamed: RL3.2 (K), RL4.1 (A)
unnamed: RL5.2 (K), RL6.1 (A)
unnamed: RL9.2 (K), RL10.1 (A)
unnamed: RL11.2 (K), RL12.1 (A)
NPLS: RL4.4 (DS1), RL5.3 (DS2), RL10.4 (DS1), RL11.3 (DS2); also elsewhere on the board
PPLS: RL3.3 (DS2), RL6.3 (DS2), RL9.3 (DS2), RL12.3 (DS2); also elsewhere on the board
SA1: RL4.3 (DS2), RL6.4 (DS1); also elsewhere on the board
SA2: RL3.4 (DS1), RL5.4 (DS1); also elsewhere on the board
SB1: RL9.4 (DS1), RL11.4 (DS1); also elsewhere on the board
SB2: RL10.3 (DS2), RL12.4 (DS1); also elsewhere on the board

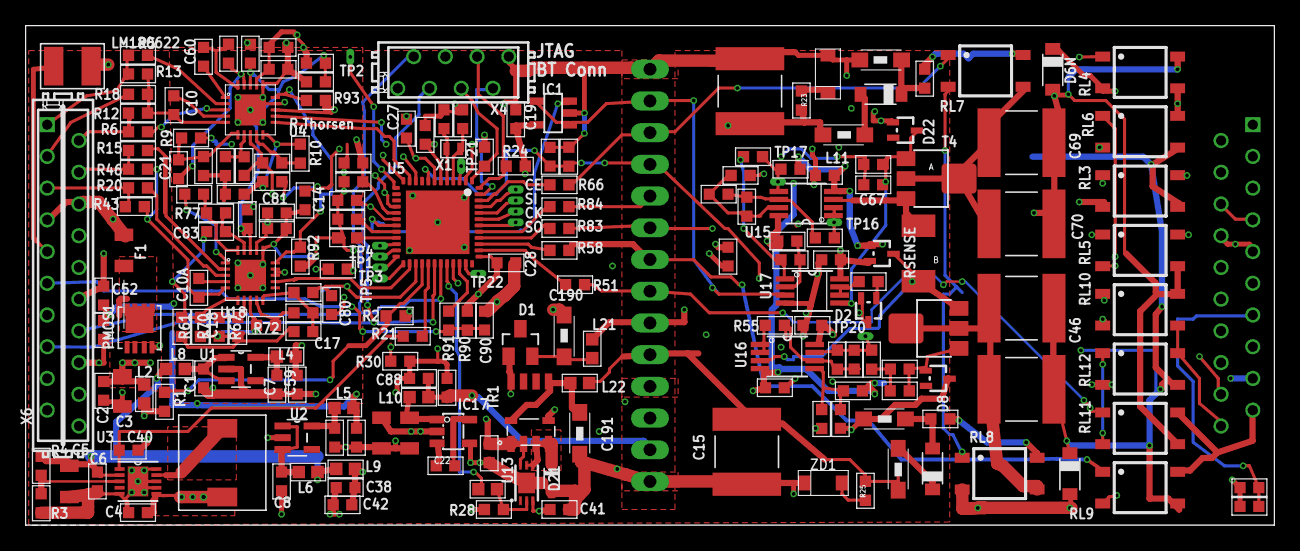
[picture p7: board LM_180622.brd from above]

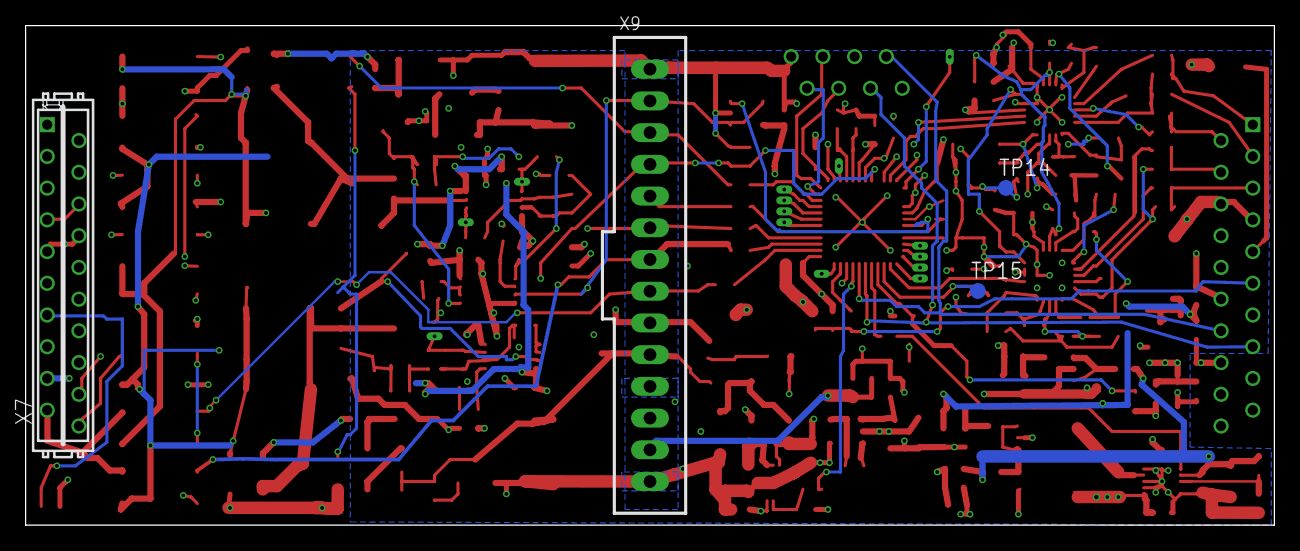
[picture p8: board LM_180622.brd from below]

Board: 4 copper layers, 100.0 x 40.0 mm, 216 parts (4 on the bottom side), 149 nets.

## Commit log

2018-12-17 First Version of the LM Hardware
    This hardware is part of a neuroprosthesis aimed at restoring hand function in people with tetraplegia.
    It is a two channel emg amplifier and a two channel functional electrical stimulator controlled by the ADUCM360 microcontroller.
    These are realized using the Eagle version 7 and produced and assembled by EuroCircuits.
    The circuits are tested and functional with some minor bug fixes.
    This part of the LM project has been supported by The Italian Ministry of Health - Ricerca Corrente, the Promobilia Foundation (Sweden) grant no 16066
    [BOM_e1029094-a.csv, LM_180622.brd, LM_180622.sch]
2019-11-04 PDF versions of the PCB layout
